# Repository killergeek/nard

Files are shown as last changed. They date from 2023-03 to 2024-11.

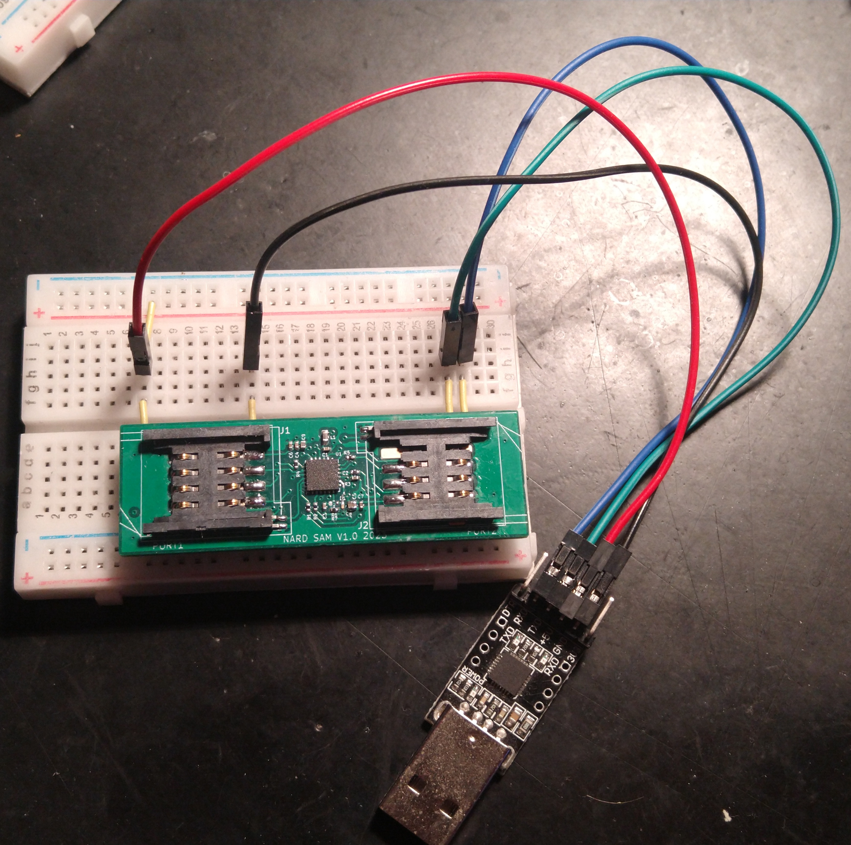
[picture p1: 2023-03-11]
pictures/nardonbreadboard.jpg

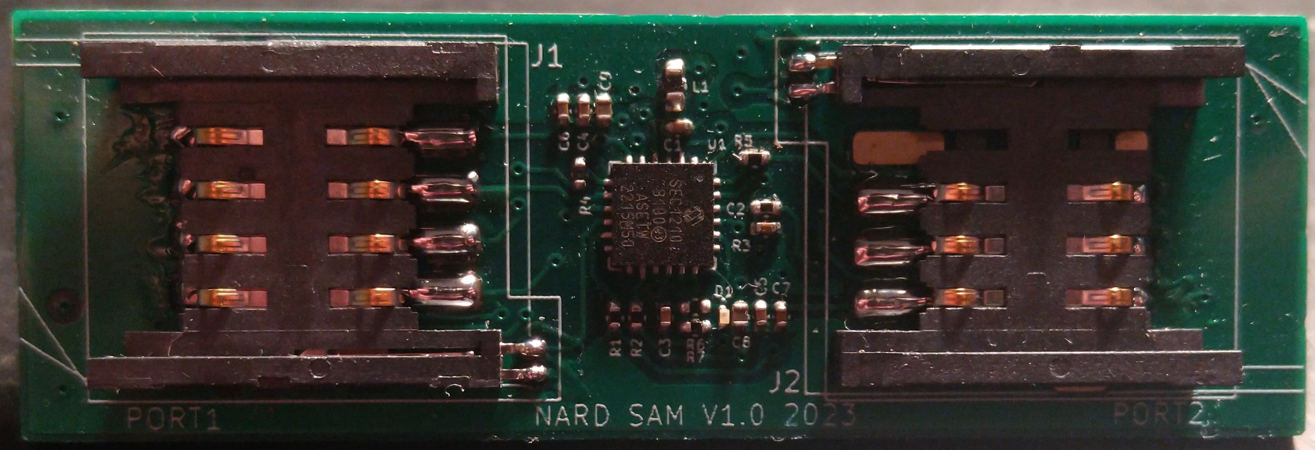
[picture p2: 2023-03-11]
pictures/frontsidenard.jpg

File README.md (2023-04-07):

# NARD
NARD: a dual sim/sam card interface for the flipper zero

# INFO
Its made to make working with smart card interface type ISO7816 easier on the flipper.\
It fits on top of the flipper with a easy breakout on the back so the IO is still available and you can plug in other modules.\
Just make sure those are not using PC0 and PC1. because those are used on the NARD.\
PC0 and PC1 are used as a serial port to communicate with the SEC1210.

When you buy the SEC1210 make sure its the UART version **not the USB!**\
And they come pre programmed with firmware from Microchip.\
And use the CCID commands to interface: https://www.usb.org/sites/default/files/DWG_Smart-Card_CCID_Rev110.pdf

For information about how to communicate with the SEC1210: https://microchip.my.site.com/s/article/SEC1210-URT--Minimal-UART-Testing-on-Windows

Example of a serial command send to the SEC1210:

See below details for this CCID command (hex):\
Hex Bytes: `03 06 62 00 00 00 00 01 01 00 00 00 67`\
*Byte 0 : SYNC (`0x03`)\
 *Byte 1 : CTRL (`0x06`)\
 *Byte 2 onwards:10 bytes of CCID header + data length: CCID command\
 *Last Byte: LRC (XOR of all the previous bytes)

so: SYNC, CTRL, <CCID commmand>, LRC

The SEC1210 information: https://www.microchip.com/en-us/product/SEC1210

sim card slot used. \
slot1: 115J-BCO0 \
slot2: 115J-ACO0 \
you can find the sim sockets by https://www.tme.eu/

slot1 has the 2 extra pads C4 and C8.

***
simple list of items used:\
\
TME.EU\
115J-ACO0 ATTEND\
115J-BCO0 ATTEND\
\
MOUSER.com\
\
855-M20-7910842R\
200-SMH11002TSTR\
81-BLM18EG221SN1D\
71-CRCW0402J-43-E3\
187-CL05A105KO5NNNC\
81-GRM155R61A104KA01\
187-CL05A106MP6NUN8\
187-CL05A106MP6NUN8\
279-CRG0402J100K/10\
71-CRCW04021M00JNEDC\
652-CR0402JW-331GLF\
579-SEC1210IPVUR2\
743-IN-S21AT5R
***

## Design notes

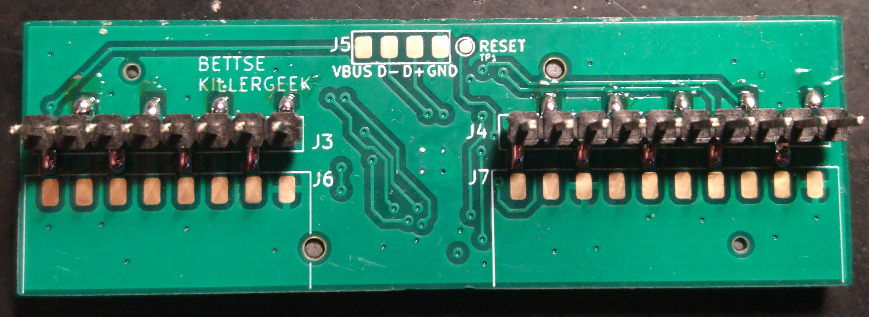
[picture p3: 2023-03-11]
pictures/backsidenard.jpg

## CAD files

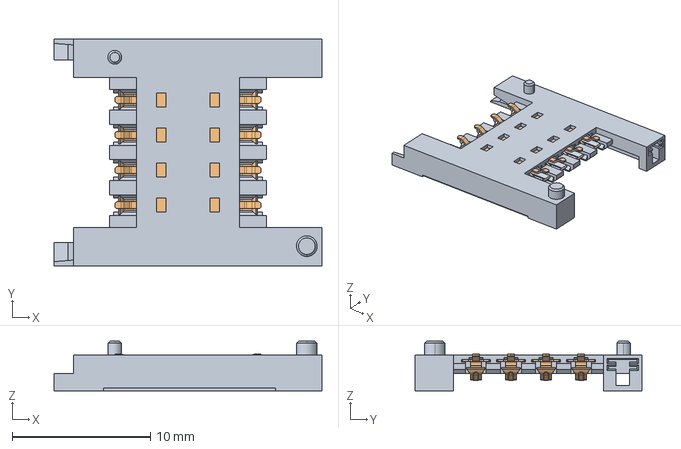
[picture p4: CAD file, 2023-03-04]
Hardware/3D_model/115c-bc00-01_C.stp
19.4 x 16.4 x 3.60 mm
HOUSING
PIN-205 x 8

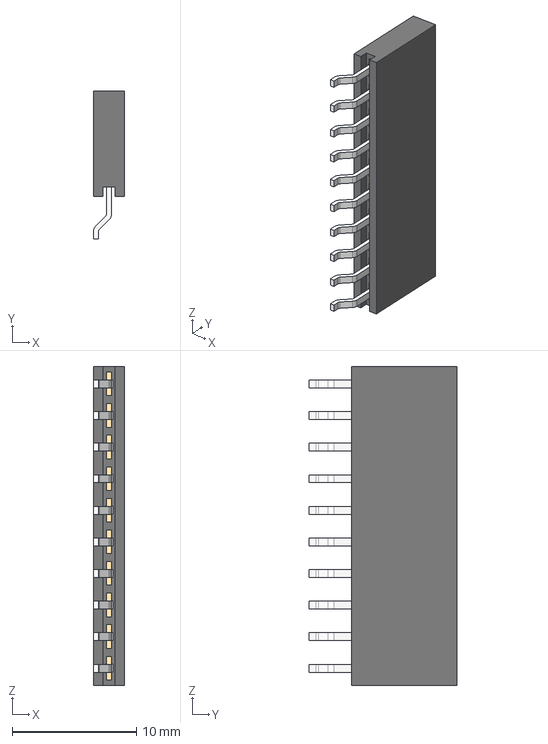
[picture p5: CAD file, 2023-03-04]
Hardware/3D_model/m20-7911042_asm.stp
2.50 x 11.9 x 25.6 mm
M20-79110_MOULD
M20-79X_CONTACT x 10

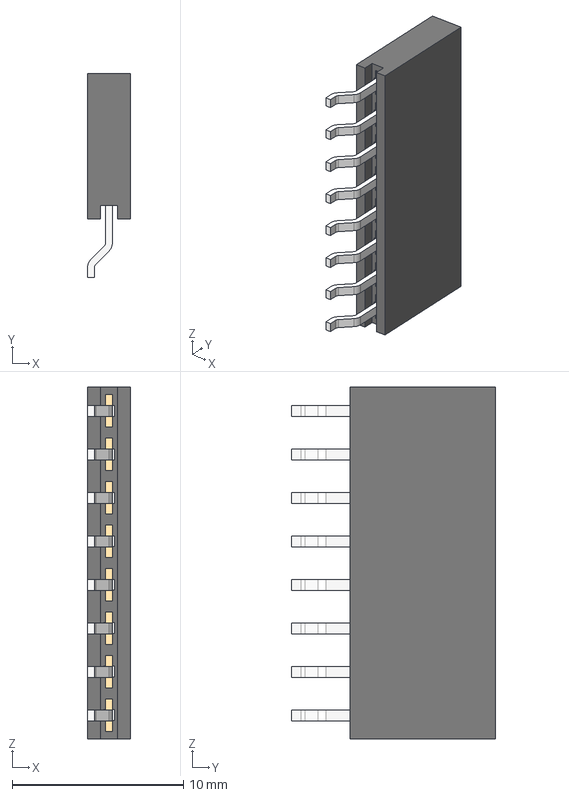
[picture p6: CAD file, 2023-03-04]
Hardware/3D_model/m20-7910842_asm.stp
2.50 x 11.9 x 20.6 mm
M20-79108_MOULD
M20-79X_CONTACT x 8

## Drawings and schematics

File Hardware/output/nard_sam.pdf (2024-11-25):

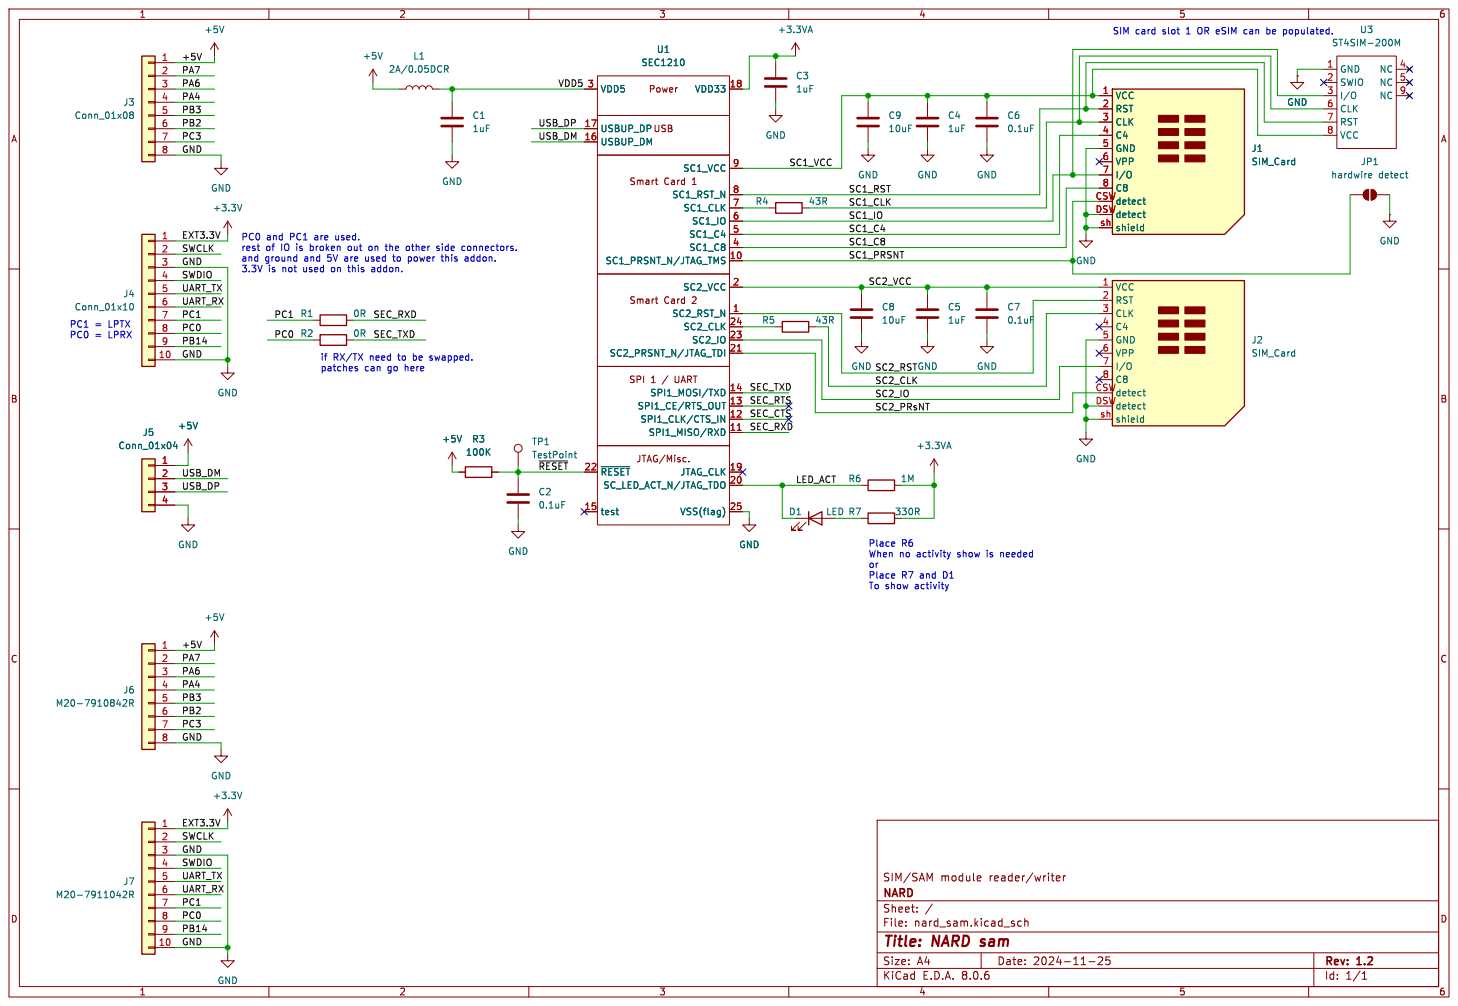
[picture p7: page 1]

1uF GND
JTAG/Misc. Power Smart Card 1 Smart Card 2 SPI 1 / UART USB

SIM card slot 1 OR eSIM can be populated. PC1 = LPTX

VCC 1 RST 2 CLK 3 C4 4 GND 5 VPP 6

J1SIM_Card VCC 1 RST 2 CLK 3 C4 4 GND 5 VPP 6

detect CSW
detect DSW
shield sh

if RX/TX need to be swapped.

or Place R7 and D1 To show activity

Id: 1/1 Title: NARD sam

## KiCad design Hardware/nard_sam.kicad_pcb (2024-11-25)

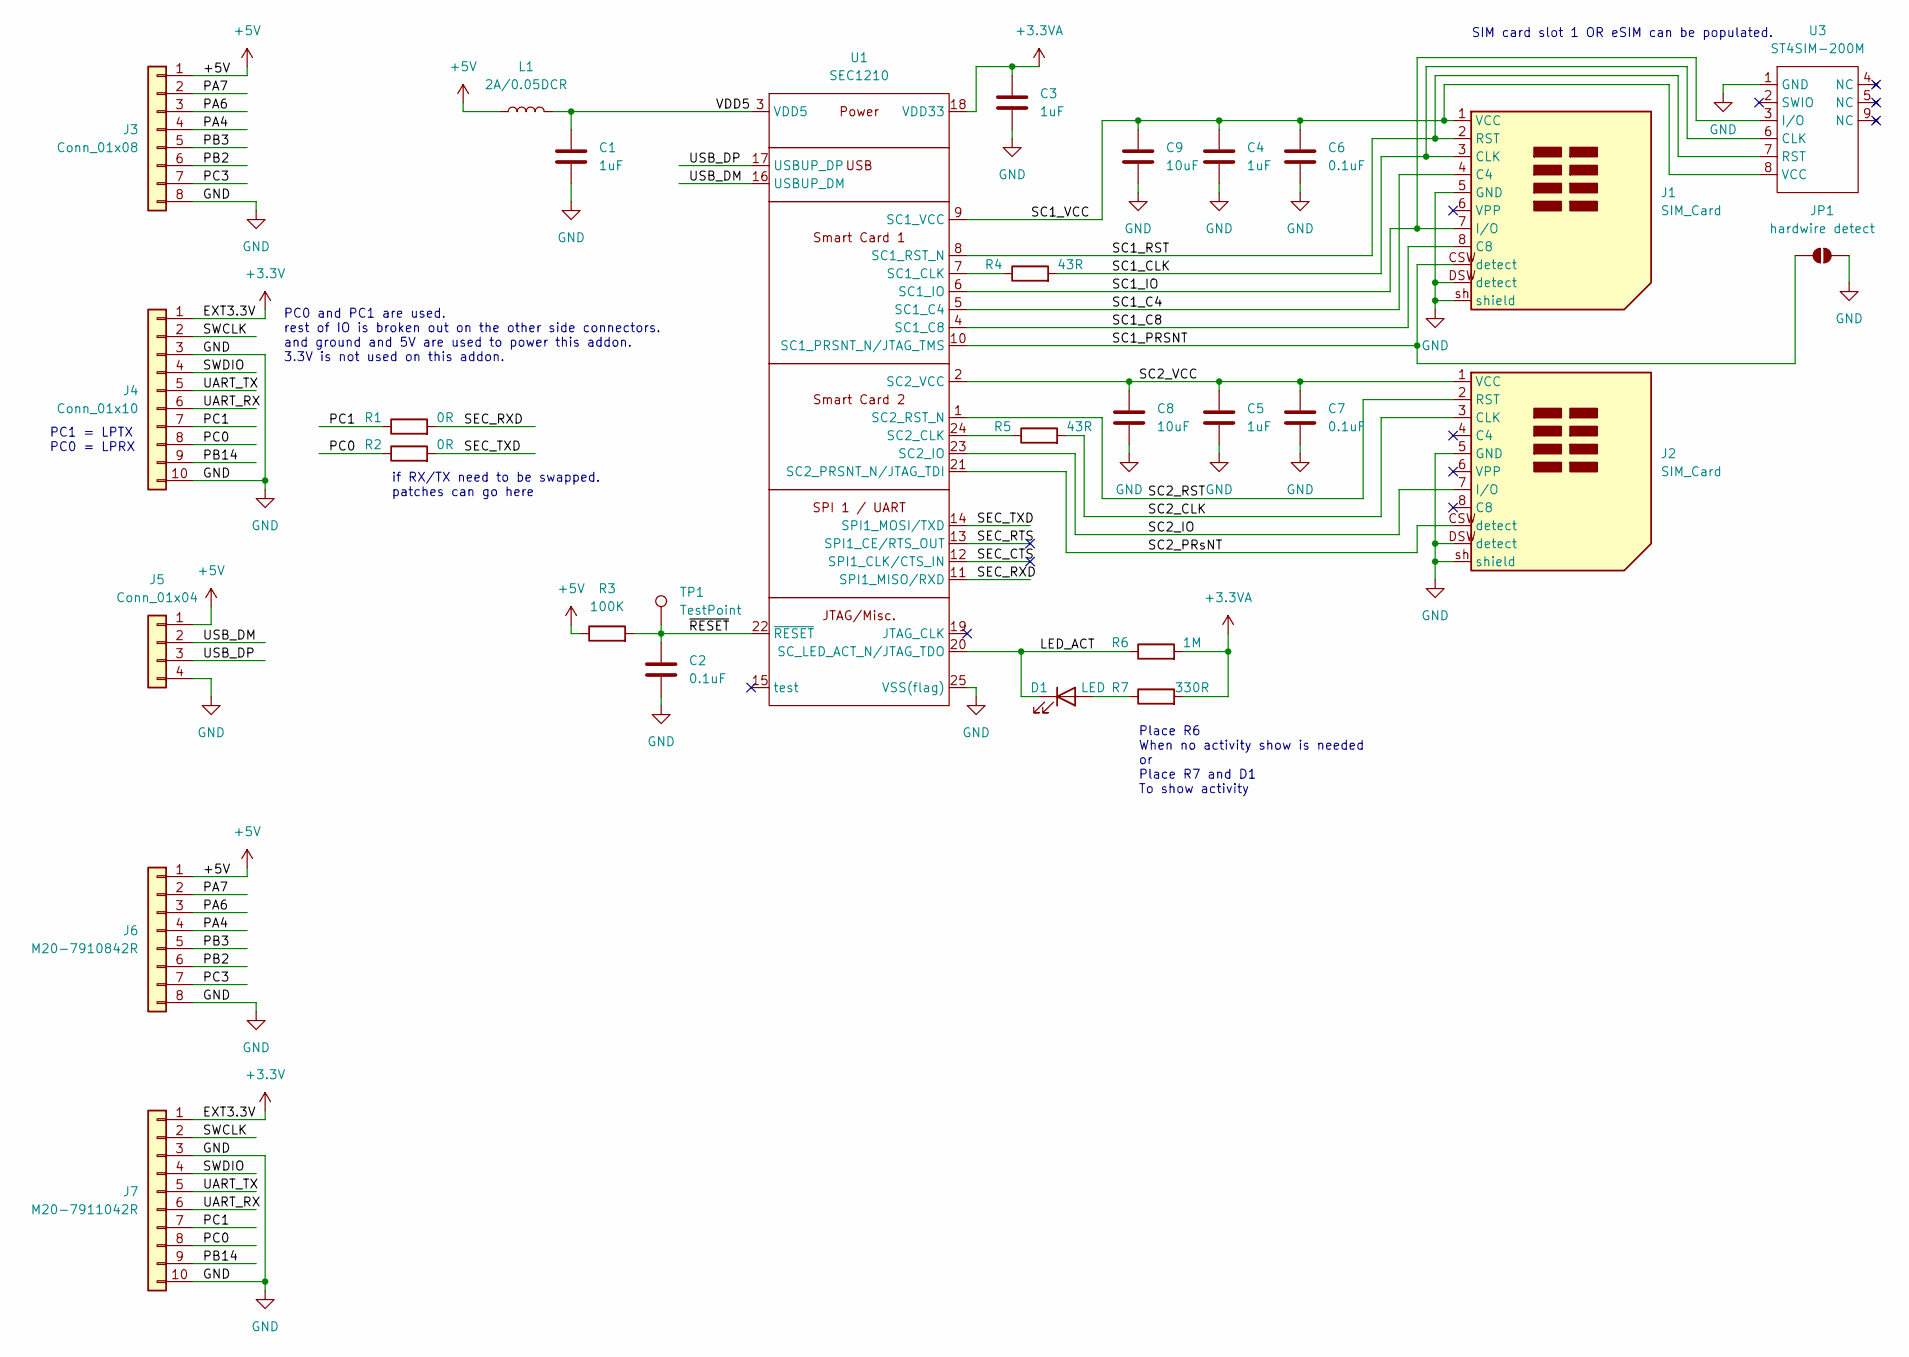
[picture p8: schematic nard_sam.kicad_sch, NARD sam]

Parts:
C1, C3, C4, C5: 1uF; C_0402_1005Metric; JLCPCB Part # C29266
C2, C6, C7: 0.1uF; C_0402_1005Metric; JLCPCB Part # C169292
C8, C9: 10uF; C_0402_1005Metric; JLCPCB Part # C3902158
D1: LED; LED_0201_0603Metric; JLCPCB Part # C3646923
J1, J2: SIM_Card; mixed_sim_sam_card_holder; JLCPCB Part # C5174695
J3: Conn_01x08; PinHeader_1x08_P2.54mm_Vertical_SMD_Pin1Left; JLCPCB Part # C2883765
J4: Conn_01x10; PinHeader_1x10_P2.54mm_Vertical_SMD_Pin1Left; JLCPCB Part # C2883767
J5: Conn_01x04; usb pads breakout
J6: M20-7910842R; m20-7910842
J7: M20-7911042R; m20-7911042
JP1: hardwire detect; SolderJumper-2_P1.3mm_Open_RoundedPad1.0x1.5mm
L1: 2A/0.05DCR; L_0603_1608Metric; JLCPCB Part # C85827
R1, R2: 0R; R_0402_1005Metric; JLCPCB Part # C21376
R3: 100K; R_0402_1005Metric; JLCPCB Part # C427222
R4, R5: 43R; R_0402_1005Metric; JLCPCB Part # C412915
R6: 1M; R_0402_1005Metric; JLCPCB Part # C427228
R7: 330R; R_0402_1005Metric; JLCPCB Part # C427206
TP1: TestPoint; TestPoint_Pad_D1.0mm
U1: SEC1210; QFN-24-1EP_5x5mm_P0.65mm_EP3.2x3.2mm; JLCPCB Part # C633309
U3: ST4SIM-200M

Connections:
+3.3V: J4.1, J7.1
+3.3VA: C3.1, R6.2, R7.2, U1.18 (VDD33)
+5V: J3.1, J5.1, J6.1, L1.1, R3.1
/LED_ACT: D1.1 (K), R6.1, U1.20 (SC_LED_ACT_N/JTAG_TDO)
/PA4: J3.4, J6.4
/PA6: J3.3, J6.3
/PA7: J3.2, J6.2
/PB2: J3.6, J6.6
/PB3: J3.5, J6.5
/PB14: J4.9, J7.9
/PC0: J4.8, J7.8, R2.1
/PC1: J4.7, J7.7, R1.1
/PC3: J3.7, J6.7
/SC1_C4: J1.4 (C4), U1.5 (SC1_C4)
/SC1_C8: J1.8 (C8), U1.4 (SC1_C8)
/SC1_CLK: J1.3 (CLK), R4.2, U3.6 (CLK)
/SC1_IO: J1.7 (I/O), U1.6 (SC1_IO), U3.3 (I/O)
/SC1_PRSNT: J1.CSW (detect), JP1.2 (B), U1.10 (SC1_PRSNT_N/JTAG_TMS)
/SC1_RST: J1.2 (RST), U1.8 (SC1_RST_N), U3.7 (RST)
/SC1_VCC: C4.1, C6.1, C9.1, J1.1 (VCC), U1.9 (SC1_VCC), U3.8 (VCC)
/SC2_CLK: J2.3 (CLK), R5.2
/SC2_IO: J2.7 (I/O), U1.23 (SC2_IO)
/SC2_PRsNT: J2.CSW (detect), U1.21 (SC2_PRSNT_N/JTAG_TDI)
/SC2_RST: J2.2 (RST), U1.1 (SC2_RST_N)
/SC2_VCC: C5.1, C7.1, C8.1, J2.1 (VCC), U1.2 (SC2_VCC)
/SEC_CTS: U1.12 (SPI1_CLK/CTS_IN)
/SEC_RTS: U1.13 (SPI1_CE/RTS_OUT)
/SEC_RXD: R1.2, U1.11 (SPI1_MISO/RXD)
/SEC_TXD: R2.2, U1.14 (SPI1_MOSI/TXD)
/SWCLK: J4.2, J7.2
/SWDIO: J4.4, J7.4
/UART_RX: J4.6, J7.6
/UART_TX: J4.5, J7.5
/USB_DM: J5.2, U1.16 (USBUP_DM)
/USB_DP: J5.3, U1.17 (USBUP_DP)
/VDD5: C1.1, L1.2, U1.3 (VDD5)
/~RESET: C2.1, R3.2, TP1.1, U1.22 (~RESET)
GND: C1.2, C2.2, C3.2, C4.2, C5.2, C6.2, C7.2, C8.2, C9.2, J1.5 (GND), J1.DSW (detect), J1.sh (shield), J2.5 (GND), J2.DSW (detect), J2.sh (shield), J3.8, J4.3, J4.10, J5.4, J6.8, J7.3, J7.10, JP1.1 (A), U1.25 (VSS(flag)), U3.1 (GND)
unnamed: D1.2 (A), R7.1
unnamed: R4.1, U1.7 (SC1_CLK)
unnamed: R5.1, U1.24 (SC2_CLK)

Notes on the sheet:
Place R6 When no activity show is needed or Place R7 and D1 To show activity
PC1 = LPTX PC0 = LPRX
if RX/TX need to be swapped. patches can go here
PC0 and PC1 are used. rest of IO is broken out on the other side connectors. and ground and 5V are used to power this addon. 3.3V is not used on this addon.
SIM card slot 1 OR eSIM can be populated.

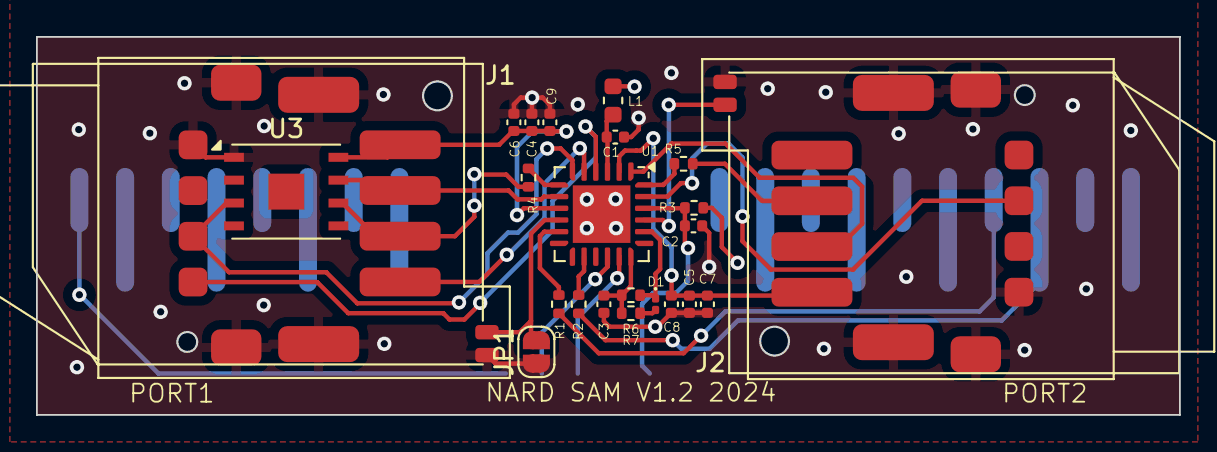
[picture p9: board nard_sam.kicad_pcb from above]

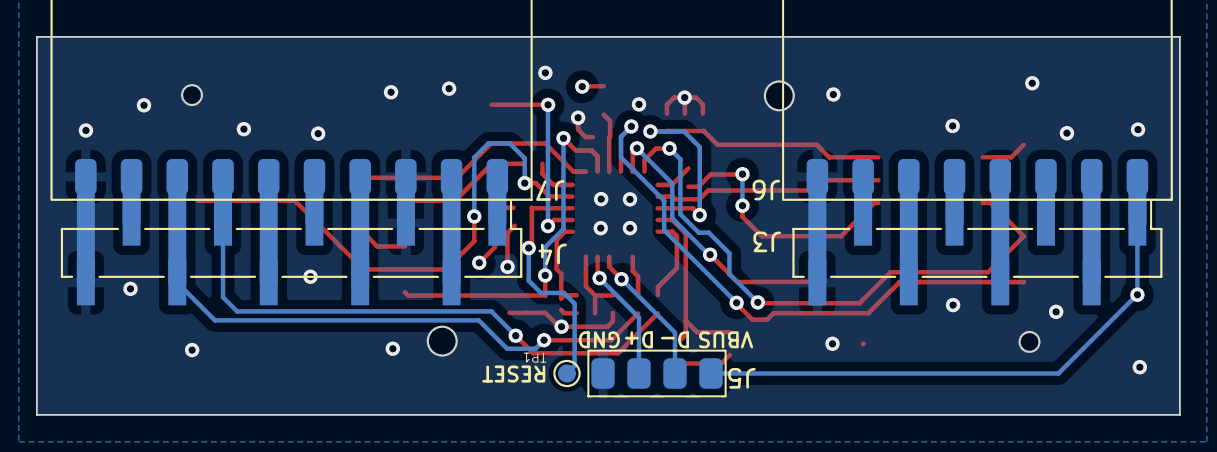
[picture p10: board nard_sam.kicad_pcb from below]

Board: 4 copper layers, 63.5 x 21.0 mm, 29 parts (6 on the bottom side), 39 nets.

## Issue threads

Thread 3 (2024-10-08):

Test module SAM via UART?

tuananh-lab, 2024-10-08:
My board contain module SAM SEC1210 only support UART.
I created /dev/ttyX via 2 GPIO ports to test communicate with module SAM.
Now what can I do next?

killergeek, 2024-11-23:
the way of communications is a bit hidden but its in the manual and here
https://microchip.my.site.com/s/article/SEC1210-URT--Minimal-UART-Testing-on-Windows

you need to send first a string of commands to instruct what the sec 1210 needs to do then you send the string with data for the sim/sam module.
depeding on what sim/sam module you have you need that datasheet to see what you need to send to it to work with it.

you can have a look at seader to get a understanding of how to interact with sam's
https://seader.ericbetts.dev/

killergeek, 2024-11-23:
and if you need a usb connection the header J5 has USB on it.

tuananh-lab, 2024-11-25:
Thank you!
Do you have any documents on porting CCID, PC/SC or communication, application development via UART port for SAM SEC1210 URT on Android?

killergeek, 2024-11-25:
no, i have made the NARD to beable to work with sim/sam modules. otheres have made software to work with this hardware.

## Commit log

2023-03-04 Added hardware design. V1.1
    [115c-bc00-01_C.stp, m20-7910842_asm.stp, m20-7911042_asm.stp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]
2023-03-05 Update README.md
    added info of the sim sockets
2023-03-11 Add files via upload
    added pictures of the board
2024-11-25 added kicad backups to gitignore
2024-11-25 update project to kicad 8.0
    [nard_sam.kicad_pcb, nard_sam.kicad_sch]
2024-11-25 added footprint for placing a eSIM chip directly on the PCB
    [nard_sam-B_Cu.gbr, nard_sam-B_Mask.gbr, nard_sam-B_Paste.gbr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]
